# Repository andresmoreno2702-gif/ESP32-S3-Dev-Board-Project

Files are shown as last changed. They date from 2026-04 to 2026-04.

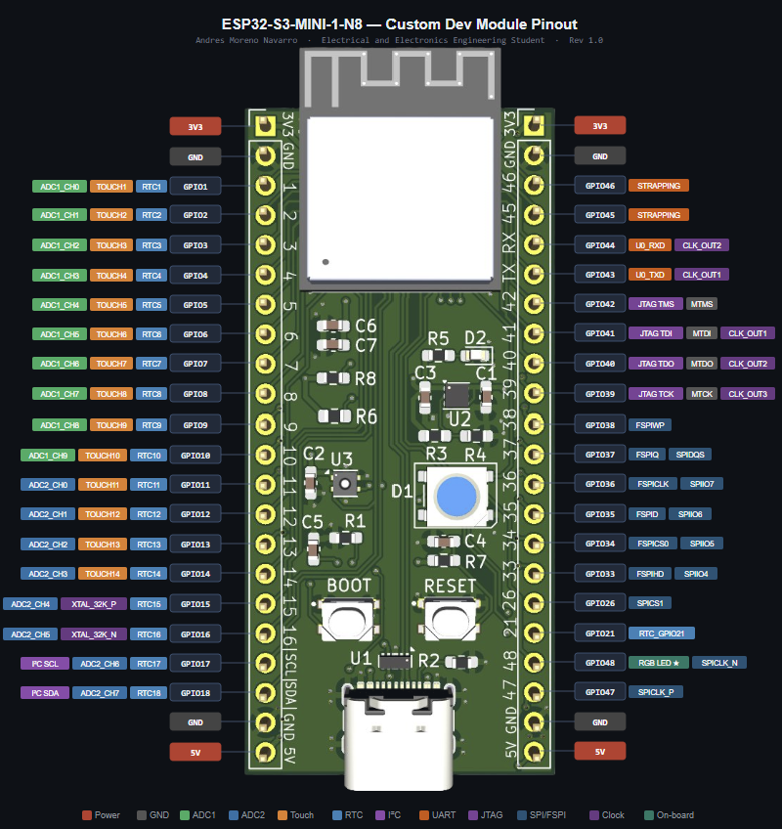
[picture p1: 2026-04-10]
Project Files/PhotosScreenshots/pinoutdevmodule.png

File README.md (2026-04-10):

# ESP32-S3 Dev Board — KiCad Project Files

Custom 4-layer ESP32-S3 development board designed in KiCad 9.
Manufactured by JLCPCB using the JLC04161H-3313 stackup.

## Contents
- /Schematic — KiCad schematic files
- /PCB — KiCad PCB layout files  
- /Gerbers — Manufacturing files for JLCPCB
- /BOM — Bill of materials

## Portfolio
Full project write-up: https://andresmoreno2702-gif.github.io/esp32-s3-project-main.html

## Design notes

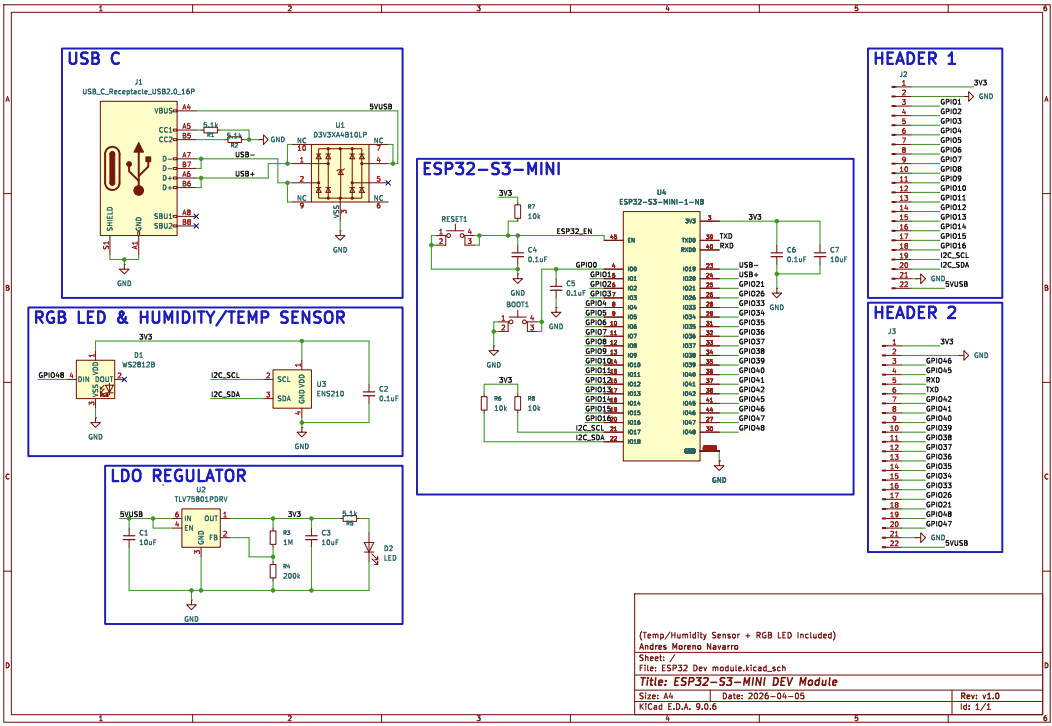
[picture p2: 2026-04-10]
Project Files/PhotosScreenshots/schematicPicture.png

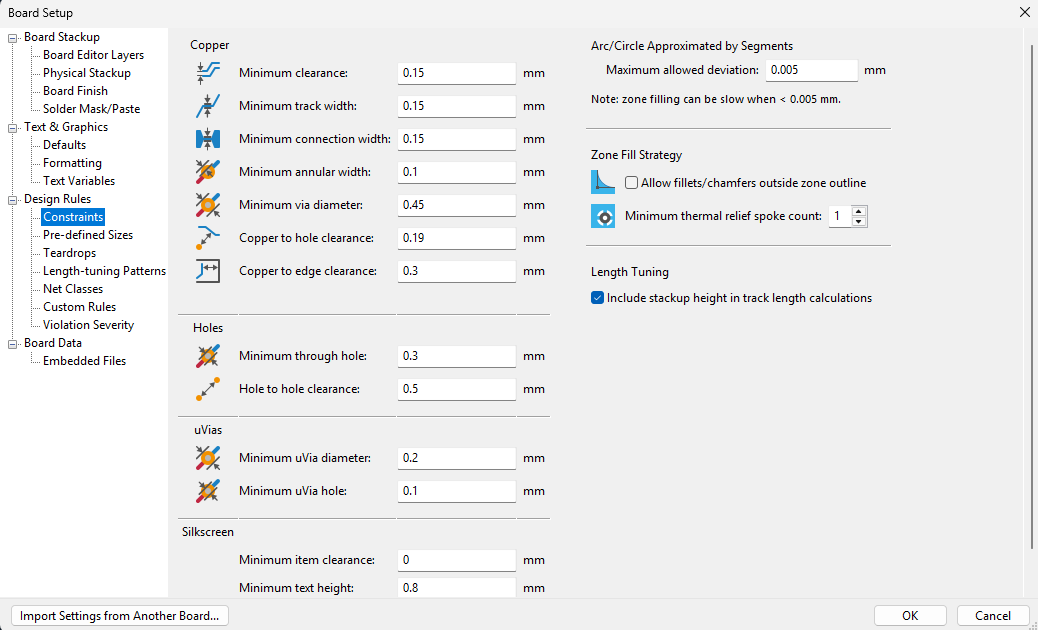
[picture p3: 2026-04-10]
Project Files/PhotosScreenshots/constraintsJLCPCB.png

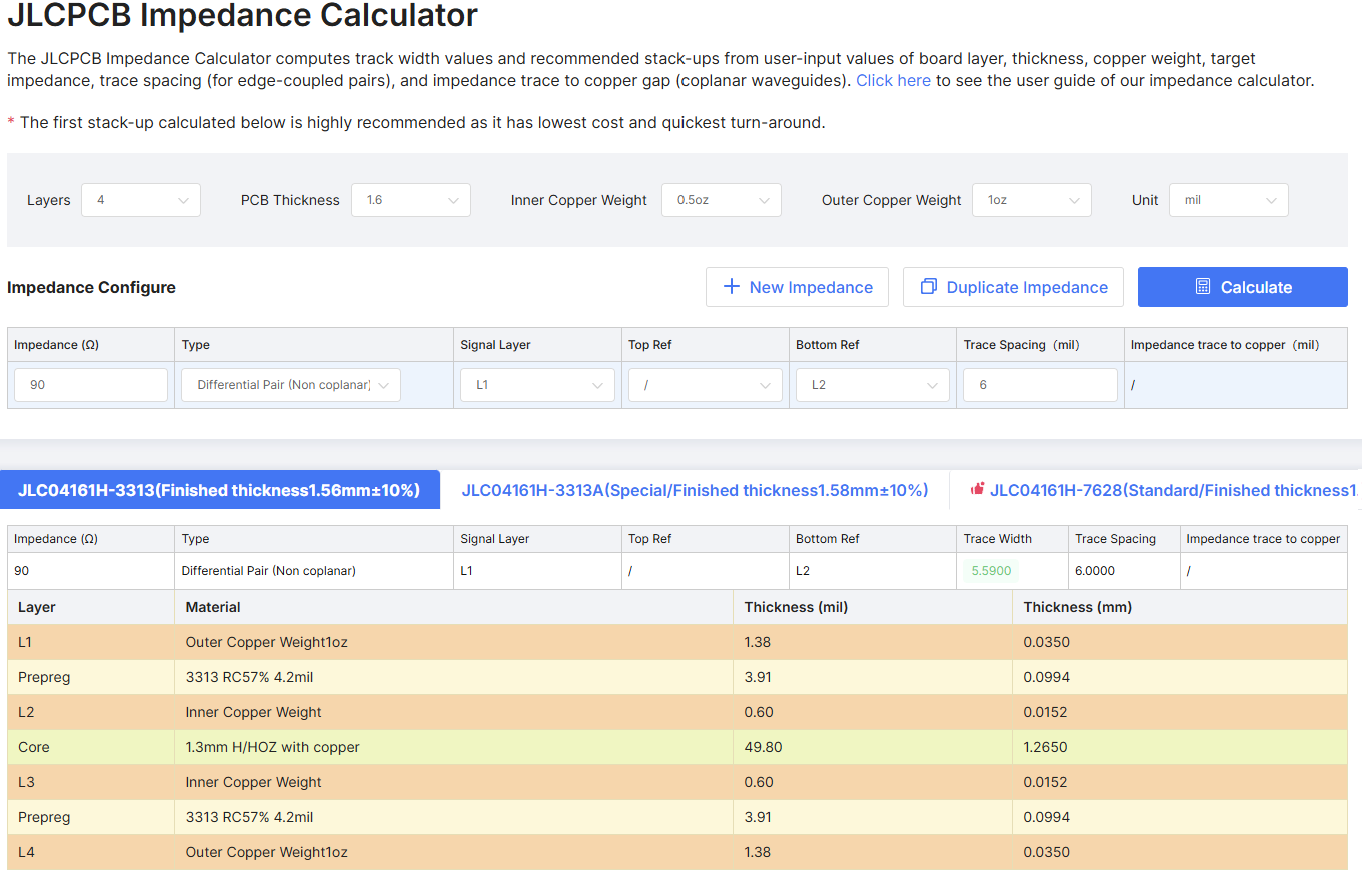
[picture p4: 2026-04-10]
Project Files/PhotosScreenshots/USB Signal Impedance CHeck.png

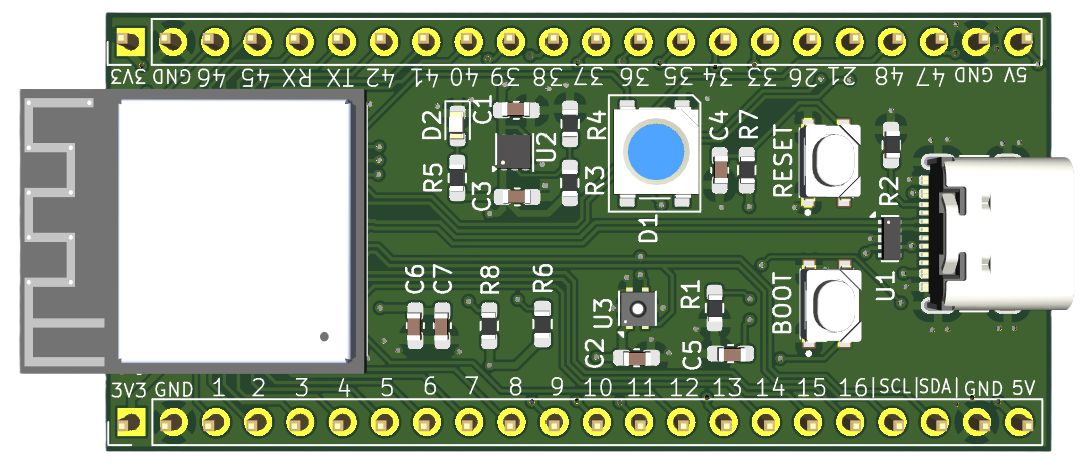
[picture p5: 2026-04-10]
Project Files/PhotosScreenshots/horizontal3dview.png

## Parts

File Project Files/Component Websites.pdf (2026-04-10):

ESP32-S3-MINI:
https://www.digikey.com/en/products/detail/espressif-systems/ESP32-S3-MINI-1-N8/15295890 (https://www.digikey.com/en/products/detail/espressif-systems/ESP32-S3-MINI-1-N8/15295890)
USB C:
https://www.digikey.com/en/models/11198441?tab=snapmagic D3V3XA4B10LP-7:
https://www.snapeda.com/parts/D3V3XA4B10LP-7/Diodes%20Inc./viewpart/?ref=search&t=D3V3XA4B10LP&ab_test_case=a (https://www.snapeda.com/parts/D3V3XA4B10LP-7/Diodes%20Inc./view-part/?t=D3V3XA4B10LP&ab_test_case=a)
LED:
https://www.digikey.com/en/products/detail/sparkfunelectronics/16347/11630204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 (https://www.digikey.com/en/products/detail/sparkfun-electronics/16347/11630204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) ENS210-LQFM (Humidity Sensor): https://www.digikey.com/en/products/detail/sciosense/ENS210-LQFM/6490747 Buttons:
https://www.digikey.com/en/products/detail/c-k/PTS810SJK250SMTR-LFS/4176611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 BfIA (https://www.digikey.com/en/products/detail/c-k/PTS810SJK250SMTR-LFS/4176611)
Primary components (chips + connector)
ESP32-S3-MINI-1-N8 module
USB4105 connector
D3V3XA4B10LP TVS protection diodes WS2812B RGB LED
TLV75801 LDO
ENS210 Temp/Humidity Sensor

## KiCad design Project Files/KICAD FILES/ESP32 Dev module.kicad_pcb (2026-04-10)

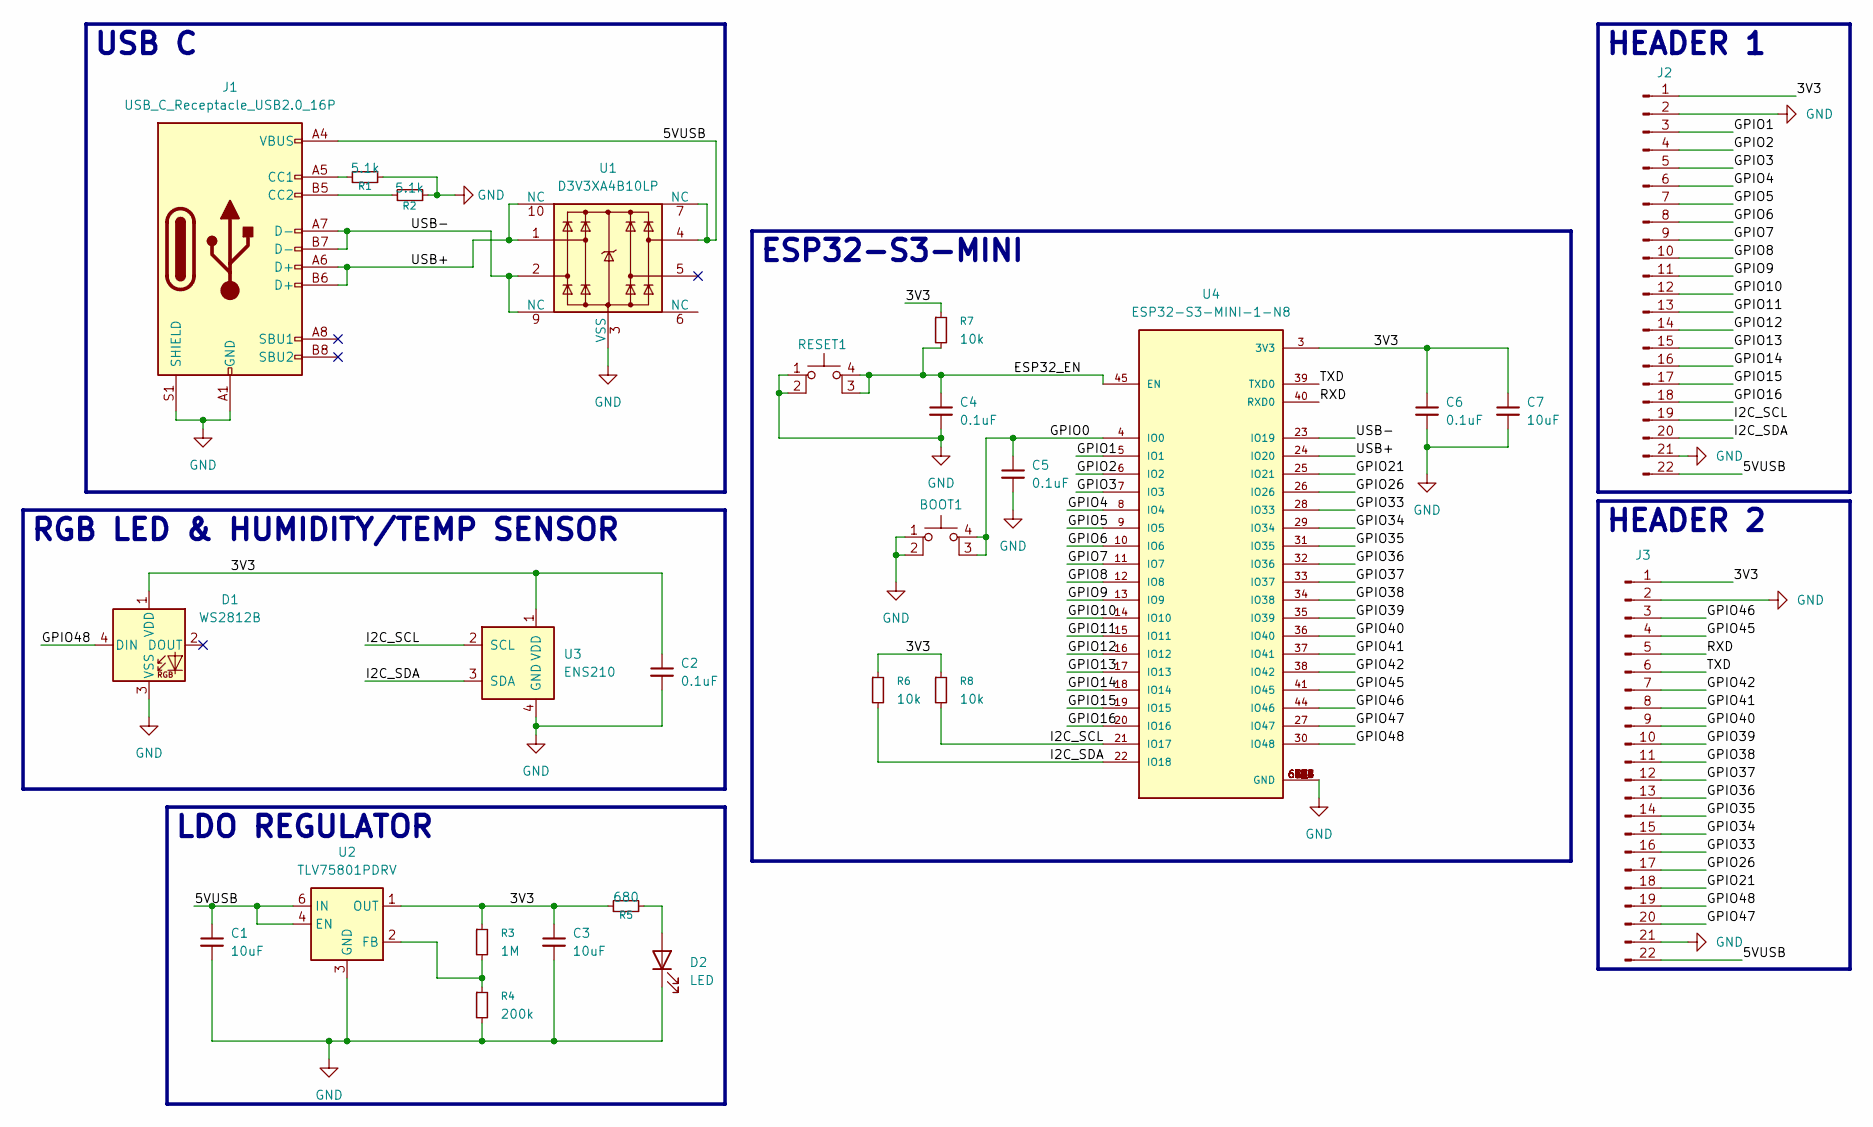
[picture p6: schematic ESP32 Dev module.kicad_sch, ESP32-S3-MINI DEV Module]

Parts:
BOOT1: SW_MEC_5E; PTS810SJG250SMTRLFS
C1, C3, C7: 10uF; C_0603_1608Metric_Pad1.08x0.95mm_HandSolder
C2, C4, C5, C6: 0.1uF; C_0603_1608Metric_Pad1.08x0.95mm_HandSolder
D1: WS2812B; LED_WS2812B_PLCC4_5.0x5.0mm_P3.2mm
D2: LED; LED_0603_1608Metric
J1: USB_C_Receptacle_USB2.0_16P; USB_C_Receptacle_GCT_USB4105-xx-A_16P_TopMnt_Horizontal
J2, J3: Conn_01x22_Pin; PinHeader_1x22_P2.54mm_Vertical
R1, R2: 5.1k; R_0603_1608Metric_Pad0.98x0.95mm_HandSolder
R3: 1M; R_0603_1608Metric_Pad0.98x0.95mm_HandSolder
R4: 200k; R_0603_1608Metric_Pad0.98x0.95mm_HandSolder
R5: 680; R_0603_1608Metric_Pad0.98x0.95mm_HandSolder
R6, R7, R8: 10k; R_0603_1608Metric_Pad0.98x0.95mm_HandSolder
RESET1: SW_MEC_5E; PTS810SJG250SMTRLFS
U1: D3V3XA4B10LP; Diodes_UDFN-10_1.0x2.5mm_P0.5mm
U2: TLV75801PDRV; WSON-6-1EP_2x2mm_P0.65mm_EP1x1.6mm
U3: ENS210; AMS_QFN-4-1EP_2x2mm_P0.95mm_EP0.7x1.6mm
U4: ESP32-S3-MINI-1-N8; PARTREV v0.6

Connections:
/3V3: C2.1, C3.1, C6.1, C7.1, D1.1 (VDD), J2.1, J3.1, R3.1, R5.1, R6.1, R7.1, R8.1, U2.1 (OUT), U3.1 (VDD), U4.3 (3V3)
/5VUSB: C1.1, J1.A4 (VBUS), J1.A9 (VBUS), J1.B4 (VBUS), J1.B9 (VBUS), J2.22, J3.22, U1.4, U1.7 (NC), U2.4 (EN), U2.6 (IN)
/ESP32_EN: C4.1, R7.2, RESET1.3 (K), RESET1.4 (A), U4.45 (EN)
/GPIO0: BOOT1.3 (K), BOOT1.4 (A), C5.1, U4.4 (IO0)
/GPIO1: J2.3, U4.5 (IO1)
/GPIO2: J2.4, U4.6 (IO2)
/GPIO3: J2.5, U4.7 (IO3)
/GPIO4: J2.6, U4.8 (IO4)
/GPIO5: J2.7, U4.9 (IO5)
/GPIO6: J2.8, U4.10 (IO6)
/GPIO7: J2.9, U4.11 (IO7)
/GPIO8: J2.10, U4.12 (IO8)
/GPIO9: J2.11, U4.13 (IO9)
/GPIO10: J2.12, U4.14 (IO10)
/GPIO11: J2.13, U4.15 (IO11)
/GPIO12: J2.14, U4.16 (IO12)
/GPIO13: J2.15, U4.17 (IO13)
/GPIO14: J2.16, U4.18 (IO14)
/GPIO15: J2.17, U4.19 (IO15)
/GPIO16: J2.18, U4.20 (IO16)
/GPIO21: J3.18, U4.25 (IO21)
/GPIO26: J3.17, U4.26 (IO26)
/GPIO33: J3.16, U4.28 (IO33)
/GPIO34: J3.15, U4.29 (IO34)
/GPIO35: J3.14, U4.31 (IO35)
/GPIO36: J3.13, U4.32 (IO36)
/GPIO37: J3.12, U4.33 (IO37)
/GPIO38: J3.11, U4.34 (IO38)
/GPIO39: J3.10, U4.35 (IO39)
/GPIO40: J3.9, U4.36 (IO40)
/GPIO41: J3.8, U4.37 (IO41)
/GPIO42: J3.7, U4.38 (IO42)
/GPIO45: J3.4, U4.41 (IO45)
/GPIO46: J3.3, U4.44 (IO46)
/GPIO47: J3.20, U4.27 (IO47)
/GPIO48: D1.4 (DIN), J3.19, U4.30 (IO48)
/I2C_SCL: J2.19, R8.2, U3.2 (SCL), U4.21 (IO17)
/I2C_SDA: J2.20, R6.2, U3.3 (SDA), U4.22 (IO18)
/RXD: J3.5, U4.40 (RXD0)
/TXD: J3.6, U4.39 (TXD0)
/USB+: J1.A6 (D+), J1.B6 (D+), U1.1, U1.10 (NC), U4.24 (IO20)
/USB-: J1.A7 (D-), J1.B7 (D-), U1.2, U1.9 (NC), U4.23 (IO19)
GND: BOOT1.1, BOOT1.2, C1.2, C2.2, C3.2, C4.2, C5.2, C6.2, C7.2, D1.3 (VSS), D2.1 (K), J1.A1 (GND), J1.A12 (GND), J1.B1 (GND), J1.B12 (GND), J1.S1 (SHIELD), J2.2, J2.21, J3.2, J3.21, R1.2, R2.2, R4.2, RESET1.1, RESET1.2, U1.3 (VSS), U1.8 (VSS), U2.3 (GND), U2.7 (GND), U3.4 (GND), U3.5 (GND), U4.1 (GND), U4.2 (GND), U4.42 (GND), U4.43 (GND), U4.46 (GND), U4.47 (GND), U4.48 (GND), U4.49 (GND), U4.50 (GND), U4.51 (GND), U4.52 (GND), U4.53 (GND), U4.54 (GND), U4.55 (GND), U4.56 (GND), U4.57 (GND), U4.58 (GND), U4.59 (GND), U4.60 (GND), U4.61 (GND), U4.61_1 (GND), U4.61_2 (GND), U4.61_3 (GND), U4.61_4 (GND), U4.61_5 (GND), U4.61_6 (GND), U4.61_7 (GND), U4.61_8 (GND), U4.62 (GND), U4.63 (GND), U4.64 (GND), U4.65 (GND)
unnamed: D2.2 (A), R5.2
unnamed: J1.A5 (CC1), R1.1
unnamed: J1.B5 (CC2), R2.1
unnamed: R3.2, R4.1, U2.2 (FB)

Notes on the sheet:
ESP32-S3-MINI
USB C
HEADER 1
LDO REGULATOR
RGB LED & HUMIDITY/TEMP SENSOR
HEADER 2

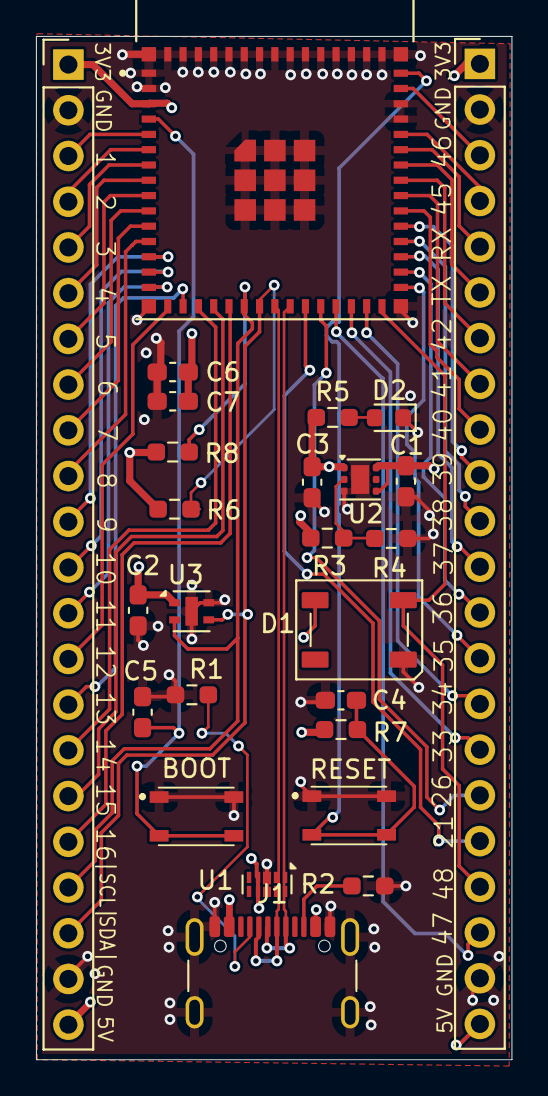
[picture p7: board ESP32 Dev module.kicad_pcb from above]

Board: 4 copper layers, 26.4 x 56.8 mm, 26 parts (0 on the bottom side), 47 nets.
